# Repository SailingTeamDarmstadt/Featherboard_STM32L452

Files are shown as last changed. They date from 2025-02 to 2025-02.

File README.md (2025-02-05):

# Featherboard_STM32L452
Our custom designed PCB for the STM32L452 in the Feather format design

# Warning
We added a charging circuit for a LiPo, but didn't test it previous to release. **If you want to use the charging circuit please check the design for yourself and make sure nothing bad can happen. You have been warned!**

## Intended use

We designed this board as a coprocessor for Marlin to control the onboard servo motors but also with a future use as an autopilot for roBOOTer. 

To keep the production cost low we chose the same STM microcontroller used throught our boats already.

## Feature list
- STM32L452RET chip
- USB-C connector for power supply and programming connection
- Additional programming header, simmilar to the one used throught our PCBs (usually not populated)
- DFU/programming jumper, to choose the chip mode
- Micro SD card slot to store/read data
- Status LEDs for power, charging, CAN and Timer usage as well as additional, free programable ones
- Access to CAN interface

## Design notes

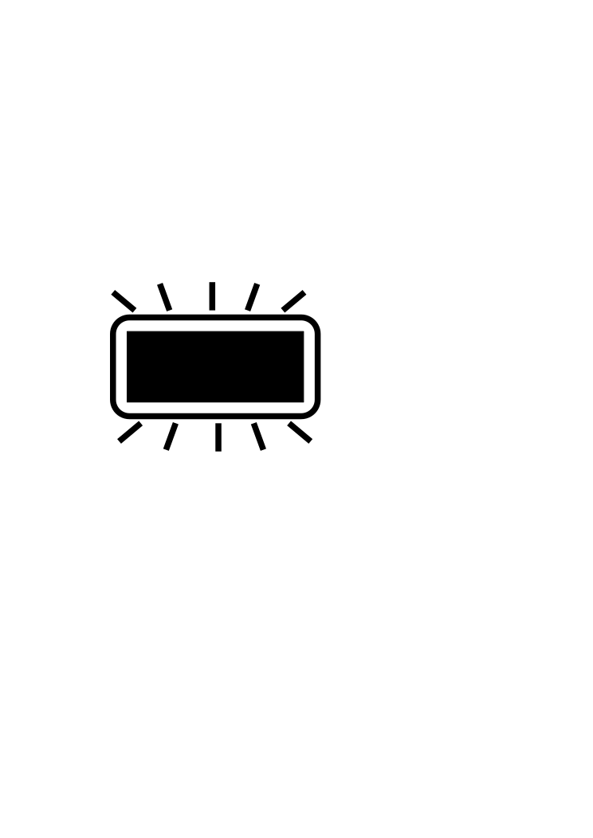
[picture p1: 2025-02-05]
Symbols/On.png

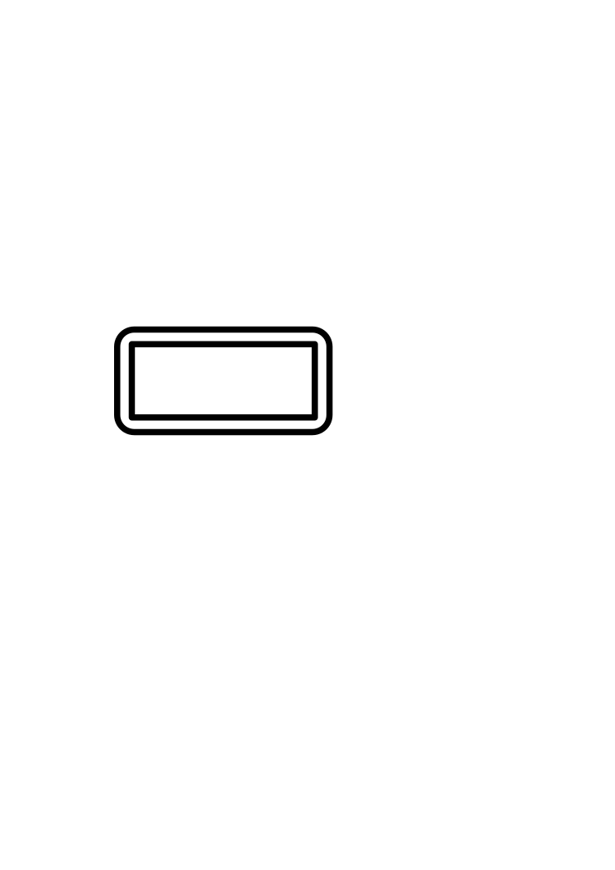
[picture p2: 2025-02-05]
Symbols/off.png

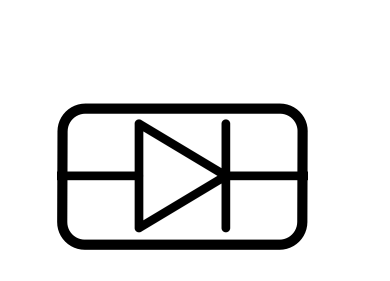
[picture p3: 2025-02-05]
Symbols/Diode_off.png

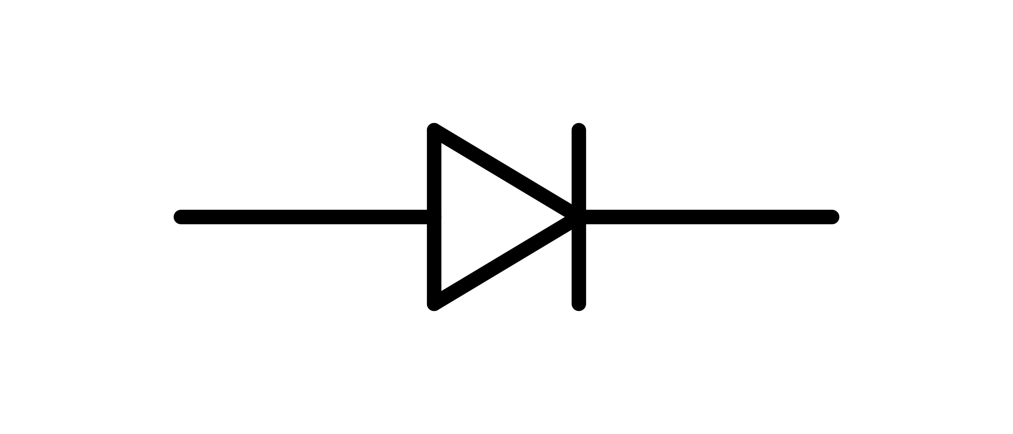
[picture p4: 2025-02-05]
Symbols/Diode_symbol.svg.png

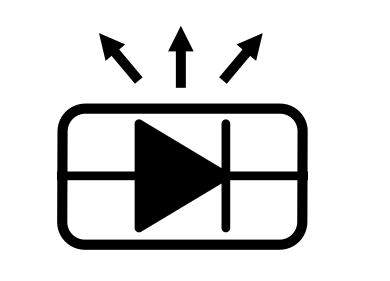
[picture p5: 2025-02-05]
Symbols/Diode_on.png

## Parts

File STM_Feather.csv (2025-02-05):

# | Reference | Qty | Value | Footprint | DNP
1 | BootJmp1 | 1 | Jumper_3_Bridged12 | Connector_PinHeader_1.27mm:PinHeader_1x03_P1.27mm_Vertical
20x "2" | C1, C2 | 2 | 1µF | Capacitor_SMD:C_0603_1608Metric_Pad1.08x0.95mm_HandSolder
20x "3" | C3 | 1 | 4.7µF | Capacitor_SMD:C_0603_1608Metric_Pad1.08x0.95mm_HandSolder
4 | C4, C5, C6, C7, C8, C11 | 6 | 100nF | Capacitor_SMD:C_0603_1608Metric_Pad1.08x0.95mm_HandSolder
20x "5" | C9 | 1 | 10µF | Capacitor_SMD:C_0603_1608Metric_Pad1.08x0.95mm_HandSolder
(20x) "6" | C12, C13 | 2 | 37pF | Capacitor_SMD:C_0603_1608Metric_Pad1.08x0.95mm_HandSolder
40x "7" | D1, D3 | 2 | LED | LED_SMD:LED_0603_1608Metric_Pad1.05x0.95mm_HandSolder
3x10x "8" | D2, D7 | 2 | D_Zener | Diode_SMD:D_0603_1608Metric_Pad1.05x0.95mm_HandSolder
9 | F1, F2, F3 | 3 | Fuse_Small | Fuse:Fuse_0603_1608Metric_Pad1.05x0.95mm_HandSolder
10 | J1 | 1 | USB_C_Receptacle_USB2.0 | Connector_USB:USB_C_Receptacle_G-Switch_GT-USB-7010ASV
11 | J2 | 1 | Conn_01x12_Female | Connector_PinSocket_2.54mm:PinSocket_1x12_P2.54mm_Vertical
12 | J3 | 1 | Conn_01x16_Female | Connector_PinSocket_2.54mm:PinSocket_1x16_P2.54mm_Vertical
5x "13" | J4 | 1 | Micro_SD_Card | Connector_Card:microSD_HC_Hirose_DM3D-SF
10x "14" | PS1 | 1 | MCP1754T-3302E_OT | PCM_Package_TO_SOT_SMD_AKL:SOT-23-5
- -"15" | R1 | 1 | 50k | Resistor_SMD:R_0603_1608Metric_Pad0.98x0.95mm_HandSolder
- -"16" | R2 | 1 | 47k | Resistor_SMD:R_0603_1608Metric_Pad0.98x0.95mm_HandSolder
- -"17" | R11, R13 | 2 | 1k | Resistor_SMD:R_0603_1608Metric_Pad0.98x0.95mm_HandSolder
- -"18" | R15 | 1 | 1M | Resistor_SMD:R_0603_1608Metric_Pad0.98x0.95mm_HandSolder
- -"19" | R16 | 1 | 10k | Resistor_SMD:R_0603_1608Metric_Pad0.98x0.95mm_HandSolder
- -"20" | R19, R20 | 2 | 5k | Resistor_SMD:R_0603_1608Metric_Pad0.98x0.95mm_HandSolder
21 | ResetBut1 | 1 | SW_Push | Button_Switch_SMD:SW_Push_SPST_NO_Alps_SKRK
- - "22" | STM32 | 1 | STM32L451RCTx | Package_QFP:LQFP-64_10x10mm_P0.5mm
5x "23" | SWD-Conn1 | 1 | ~ | Connector_PinHeader_2.54mm:PinHeader_2x05_P2.54mm_Vertical_SMD
10x "24" | Y1-2NM08000C33YC1 | 1 | 8 MHz | Oscillator:Oscillator_SMD_ECS_2520MV-xxx-xx-4Pin_2.5x2.0mm

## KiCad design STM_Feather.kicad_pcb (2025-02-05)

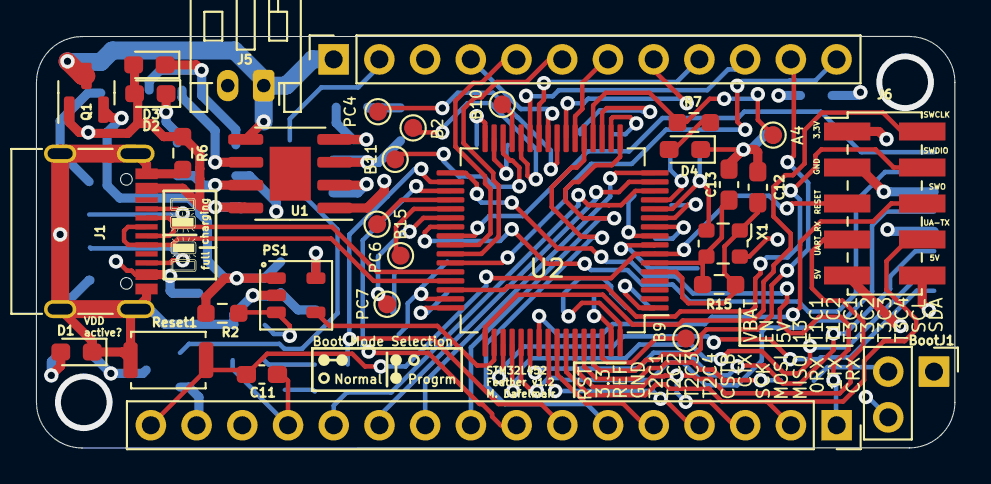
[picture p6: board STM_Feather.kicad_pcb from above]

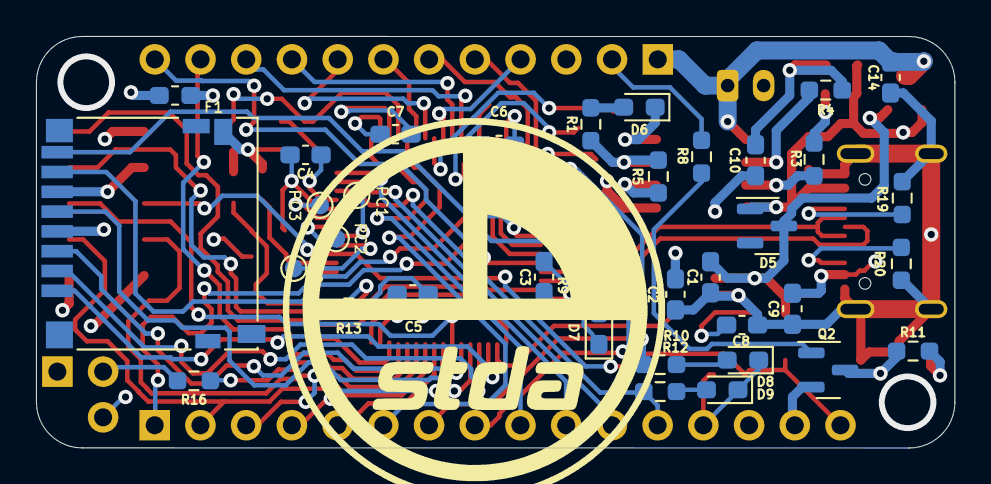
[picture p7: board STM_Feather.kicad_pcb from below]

Board: 4 copper layers, 51.0 x 22.9 mm, 68 parts (36 on the bottom side), 75 nets.

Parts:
A4: TestPoint; TestPoint_Pad_D1.0mm
B2, B9, B10, B11, B15: TestPoint; TestPoint_Pad_D1.0mm
BootJ1: Jumper_3_Bridged12; PinHeader_1x03_P2.54mm_90Degr
C1, C2: 1µF; C_0603_1608Metric_Pad1.08x0.95mm_HandSolder
C3: 4.7µF; C_0603_1608Metric_Pad1.08x0.95mm_HandSolder
C4, C5, C6, C7, C8, C11: 100nF; C_0603_1608Metric_Pad1.08x0.95mm_HandSolder
C9, C10, C14: 10µF; C_0603_1608Metric_Pad1.08x0.95mm_HandSolder
C12, C13: 37pF; C_0603_1608Metric_Pad1.08x0.95mm_HandSolder
D1, D2, D3, D4, D7, D8, D9: LED; LED_0603_1608Metric_Pad1.05x0.95mm_HandSolder
D5: ZHCS1000; SOT-23
D6: D_Zener; D_0603_1608Metric_Pad1.05x0.95mm_HandSolder
F1: Fuse_Small; Fuse_0603_1608Metric_Pad1.05x0.95mm_HandSolder
J1: USB_C_Receptacle_USB2.0; USB_C_Receptacle_G-Switch_GT-USB-7010ASV
J2: Conn_01x12_Female; PinSocket_1x12_P2.54mm_Vertical
J3: Conn_01x16_Female; PinSocket_1x16_P2.54mm_Vertical
J4: Micro_SD_Card; microSD_HC_Hirose_DM3D-SF
J5: Conn_01x02; JST_PH_S2B-PH-K_1x02_P2.00mm_Horizontal
J6: Conn_02x05_Odd_Even; PinHeader_2x05_P2.00mm_Vertical_SMD
PC0, PC1, PC2, PC3, PC4, PC6, PC7: TestPoint; TestPoint_Pad_D1.0mm
PS1: MCP1754T-3302E_OT; SOT-23-5
Q1, Q2: DMG1045U; SOT-23
R1: 50k; R_0603_1608Metric_Pad0.98x0.95mm_HandSolder
R2: 47k; R_0603_1608Metric_Pad0.98x0.95mm_HandSolder
R3, R4, R7, R9, R10, R11, R12: 1k; R_0603_1608Metric_Pad0.98x0.95mm_HandSolder
R5: 5k; R_0603_1608Metric_Pad0.98x0.95mm_HandSolder
R6: 100k; R_0603_1608Metric_Pad0.98x0.95mm_HandSolder
R8, R16: 10k; R_0603_1608Metric_Pad0.98x0.95mm_HandSolder
R13: 0; R_0603_1608Metric_Pad0.98x0.95mm_HandSolder
R15: 1M; R_0603_1608Metric_Pad0.98x0.95mm_HandSolder
R19, R20: 5,1k; R_0603_1608Metric_Pad0.98x0.95mm_HandSolder
Reset1: SW_Push; SW_Push_SPST_NO_Alps_SKRK
U1: TP4056; SOIC-8-1EP_3.9x4.9mm_P1.27mm_EP2.29x3mm
U2: STM32L452RETx; LQFP-64_10x10mm_P0.5mm
X1: ECS-2520MV-xxx-xx; Oscillator_SMD_ECS_2520MV-xxx-xx-4Pin_2.5x2.0mm

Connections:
3Vsup: J3.15, Q2.2 (S)
+BATT: C14.2, J2.1, J5.1, Q1.3 (D), U1.5 (BAT)
/0 RX: J3.3, J6.7, U2.59 (PB7)
/1 TX: J3.2, J6.8, U2.58 (PB6)
/5: J2.10, U2.27 (PB1)
/6: J2.9, U2.26 (PB0)
/9: J2.8, U2.23 (PA7)
/10: J2.7, U2.22 (PA6)
/11: J2.6, U2.42 (PA9)
/12: J2.5, U2.41 (PA8)
/A0: J3.12, R12.1, U2.14 (PA0)
/A1: J3.11, U2.15 (PA1)
/A2: J3.10, U2.16 (PA2)
/A3: J3.9, U2.17 (PA3)
/A4: J3.8, U2.35 (PB14)
/A5: J3.7, R10.1, U2.34 (PB13)
/CAN1_RX: J3.1, U2.33 (PB12)
/Ext_5V: F1.1, J6.9, J6.10
/I2C1_SCL: J2.11, U2.61 (PB8)
/I2C1_SDA: J2.12, U2.43 (PA10)
/MISO: J3.4, U2.56 (PB4)
/MOSI: J3.5, U2.57 (PB5)
/SCK: J3.6, U2.21 (PA5)
/SDMMC1_CK: J4.5 (CLK), U2.53 (PC12)
/SDMMC1_CMD: J4.3 (CMD), U2.54 (PD2)
/SDMMC1_D0: J4.7 (DAT0), U2.39 (PC8)
/SDMMC1_D1: J4.8 (DAT1), U2.40 (PC9)
/SDMMC1_D2: J4.1 (DAT2), U2.51 (PC10)
/SDMMC1_D3: J4.2 (DAT3/CD), U2.52 (PC11)
/SYS_JMTS-SWDIO: J6.4, U2.46 (PA13)
/SYS_JTCK-SWCLK: J6.2, U2.49 (PA14)
/SYS_JTDI: B15.1, U2.36 (PB15)
/SYS_JTDO-SWO: J6.6, U2.55 (PB3)
/USB_DM: J1.A7 (D-), J1.B7 (D-), U2.44 (PA11)
/USB_DP: J1.A6 (D+), J1.B6 (D+), U2.45 (PA12)
ADC-WKUP: J2.4, U2.25 (PC5)
BOOT: R16.1, U2.60 (PH3)
EN: J2.2, R8.1
GND: BootJ1.3 (B), C1.2, C2.2, C3.2, C4.2, C5.2, C6.2, C7.2, C8.2, C9.2, C10.1, C11.2, C12.1, C13.2, C14.1, D1.1 (K), D4.1 (K), D7.1 (K), D8.1 (K), D9.1 (K), J1.A1 (GND), J1.A12 (GND), J1.B1 (GND), J1.B12 (GND), J1.S1 (SHIELD), J3.13, J4.6 (VSS), J4.9 (SHIELD), J5.2, J6.3, PS1.2 (GND), R1.2, R5.1, R6.2, R19.1, R20.1, Reset1.1, U1.1 (TEMP), U1.3 (GND), U2.12 (VSSA), U2.18 (VSS), U2.31 (VSS), U2.47 (VSS), U2.63 (VSS), X1.2 (GND)
unnamed: BootJ1.2 (C), R16.2
unnamed: D1.2 (A), R11.2
unnamed: D2.1 (K), R3.1
unnamed: C10.2, D3.1 (K), R4.1
unnamed: D4.2 (A), R7.1
unnamed: D6.2 (A), R1.1
unnamed: D7.2 (A), R9.1
unnamed: D8.2 (A), R10.2
unnamed: D9.2 (A), R12.2
unnamed: J1.A5 (CC1), R19.2
unnamed: J1.B5 (CC2), R20.2
unnamed: C8.1, PS1.3 (~SHDN), R2.2
unnamed: Q2.1 (G), R8.2
unnamed: R5.2, U1.2 (PROG)
unnamed: R3.2, U1.7 (~CHRG)
unnamed: R4.2, U1.6 (~STDBY)
unnamed: A4.1, R7.2, U2.20 (PA4)
unnamed: B2.1, U2.28 (PB2)
unnamed: B9.1, U2.62 (PB9)
unnamed: B10.1, U2.29 (PB10)
unnamed: B11.1, U2.30 (PB11)
unnamed: PC0.1, U2.8 (PC0)
unnamed: PC1.1, U2.9 (PC1)
unnamed: PC2.1, U2.10 (PC2)
unnamed: PC3.1, U2.11 (PC3)
unnamed: PC4.1, U2.24 (PC4)
unnamed: PC6.1, U2.37 (PC6)
unnamed: PC7.1, R9.2, U2.38 (PC7)
unnamed: R13.1, U2.1 (VBAT)
OSC_IN: C12.2, R15.1, U2.5 (PH0), X1.1 (Tri-State)
OSC_OUT: C13.1, R15.2, U2.6 (PH1), X1.3 (OUT)
RESET: C11.1, J3.16, J6.5, Reset1.2, U2.7 (NRST)
UV_DET: PS1.4 (PWRGD), U2.50 (PA15)
VBUS: C9.1, D2.2 (A), D3.2 (A), D5.1 (A), D6.1 (K), F1.2, J1.A4 (VBUS), J1.A9 (VBUS), J1.B4 (VBUS), J1.B9 (VBUS), J2.3, Q1.1 (G), R6.1, U1.4 (VCC), U1.8 (CE)
VCC: C1.1, D5.3 (K), PS1.1 (VIN), Q1.2 (S), R2.1
VDD: BootJ1.1 (A), C2.1, C3.1, C4.1, C5.1, C6.1, C7.1, J4.4 (VDD), J6.1, PS1.5 (VOUT), Q2.3 (D), R11.1, R13.2, U2.13 (VDDA), U2.19 (VDD), U2.32 (VDD), U2.48 (VDDUSB), U2.64 (VDD), X1.4 (VDD)
